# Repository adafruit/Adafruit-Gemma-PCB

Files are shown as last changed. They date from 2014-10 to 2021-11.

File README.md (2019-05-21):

## Adafruit Gemma Classic (ATtiny85) PCB
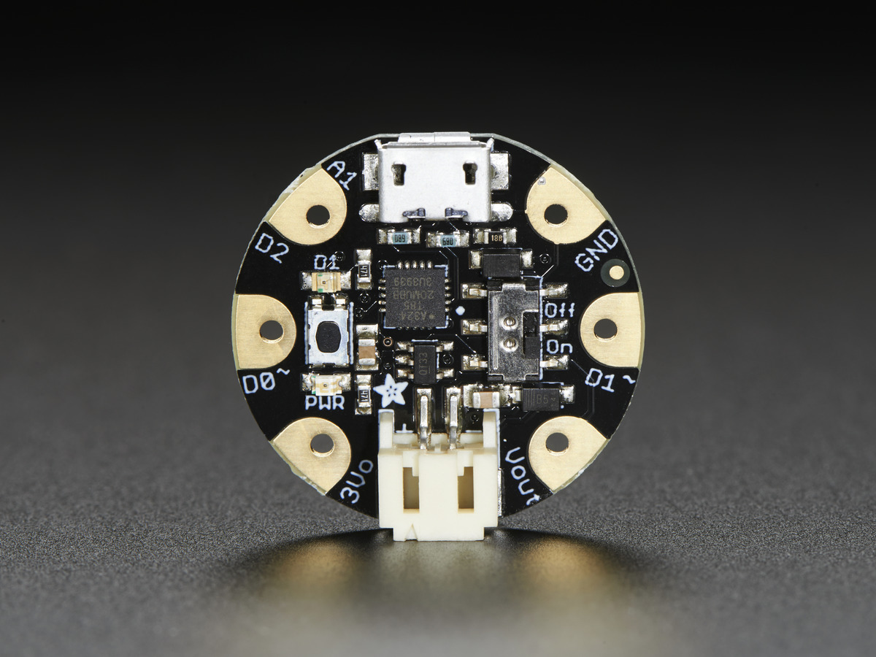
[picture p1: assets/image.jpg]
<a href="http://www.adafruit.com/products/1222"><br/>
Click here to purchase one from the Adafruit shop</a>

Deprecation Warning: The Gemma bit-bang USB technique it uses doesn't work as well as it did in 2014, many modern computers won't work well. So while we still carry the Gemma so that people can maintain some older projects, we no longer recommend it. Please check out the Gemma M0. It has built-in USB, more capabilities, and is comparable in price!

GEMMA is a tiny wearable platform board with a lot of might in a 1" diameter package. Powered by a Attiny85 and programmable with an Arduino IDE over USB, you'll be able to realize any wearable project!

We wanted to design a microcontroller board that was small enough to fit into any project, and low cost enough to use without hesitation. Perfect for when you don't want to give up your Flora and you aren't willing to take apart the project you worked so hard to design. It's our lowest-cost sewable controller!

The Attiny85 is a fun processor because despite being so small, it has 8K of flash, and 5 I/O pins, including analog inputs and PWM 'analog' outputs. We designed a USB bootloader so you can plug it into any computer and reprogram it over a USB port just like an Arduino (it uses 2 of the 5 I/O pins, leaving you with 3). In fact we even made some simple modifications to the Arduino IDE so that it works like a mini-Flora. Perfect for small & simple projects the GEMMA will be your go-to wearable electronics platform.

This is the CAD & PCB data for the Adafruit Gemma. The PCB format is EagleCAD schematic and board layout

For more details, check out the product page at
- https://www.adafruit.com/products/1222

### License

Adafruit invests time and resources providing this open source design, please support Adafruit and open-source hardware by purchasing products from [Adafruit](https://www.adafruit.com)!

All text above must be included in any redistribution

Designed by Limor Fried/Ladyada for Adafruit Industries.
Creative Commons Attribution/Share-Alike, all text above must be included in any redistribution. 
See license.txt for additional information.

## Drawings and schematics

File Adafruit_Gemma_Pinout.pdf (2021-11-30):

# Gemma

# https://www.adafruit.com/products/1222

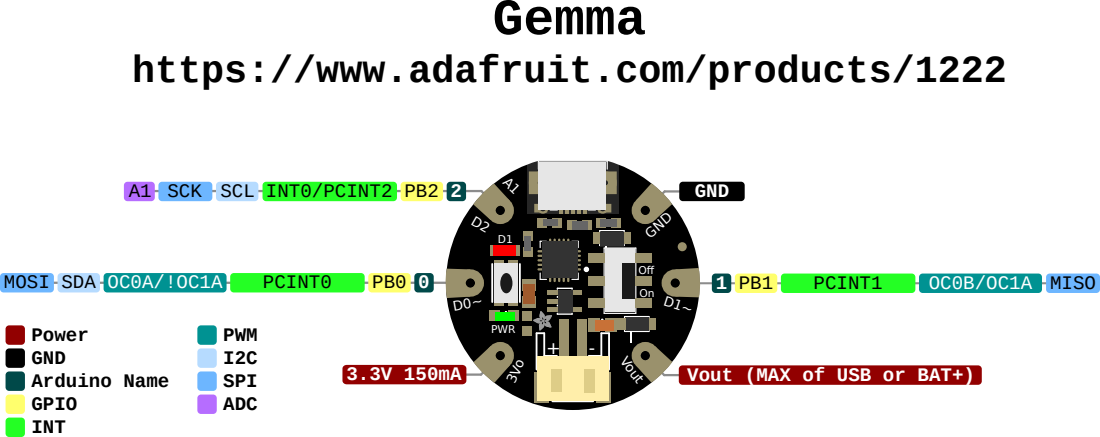
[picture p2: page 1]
PCINT1; OC0B/OC1A MISO; GND; A1 SCK SCL INT0/PCINT2 PB2 2; MOSI SDA OC0A/!OC1A; PCINT0; Vout; PWR; Off; Power GND Arduino Name GPIO INT; PWM I2C SPI ADC

Vout (MAX of USB or BAT+)

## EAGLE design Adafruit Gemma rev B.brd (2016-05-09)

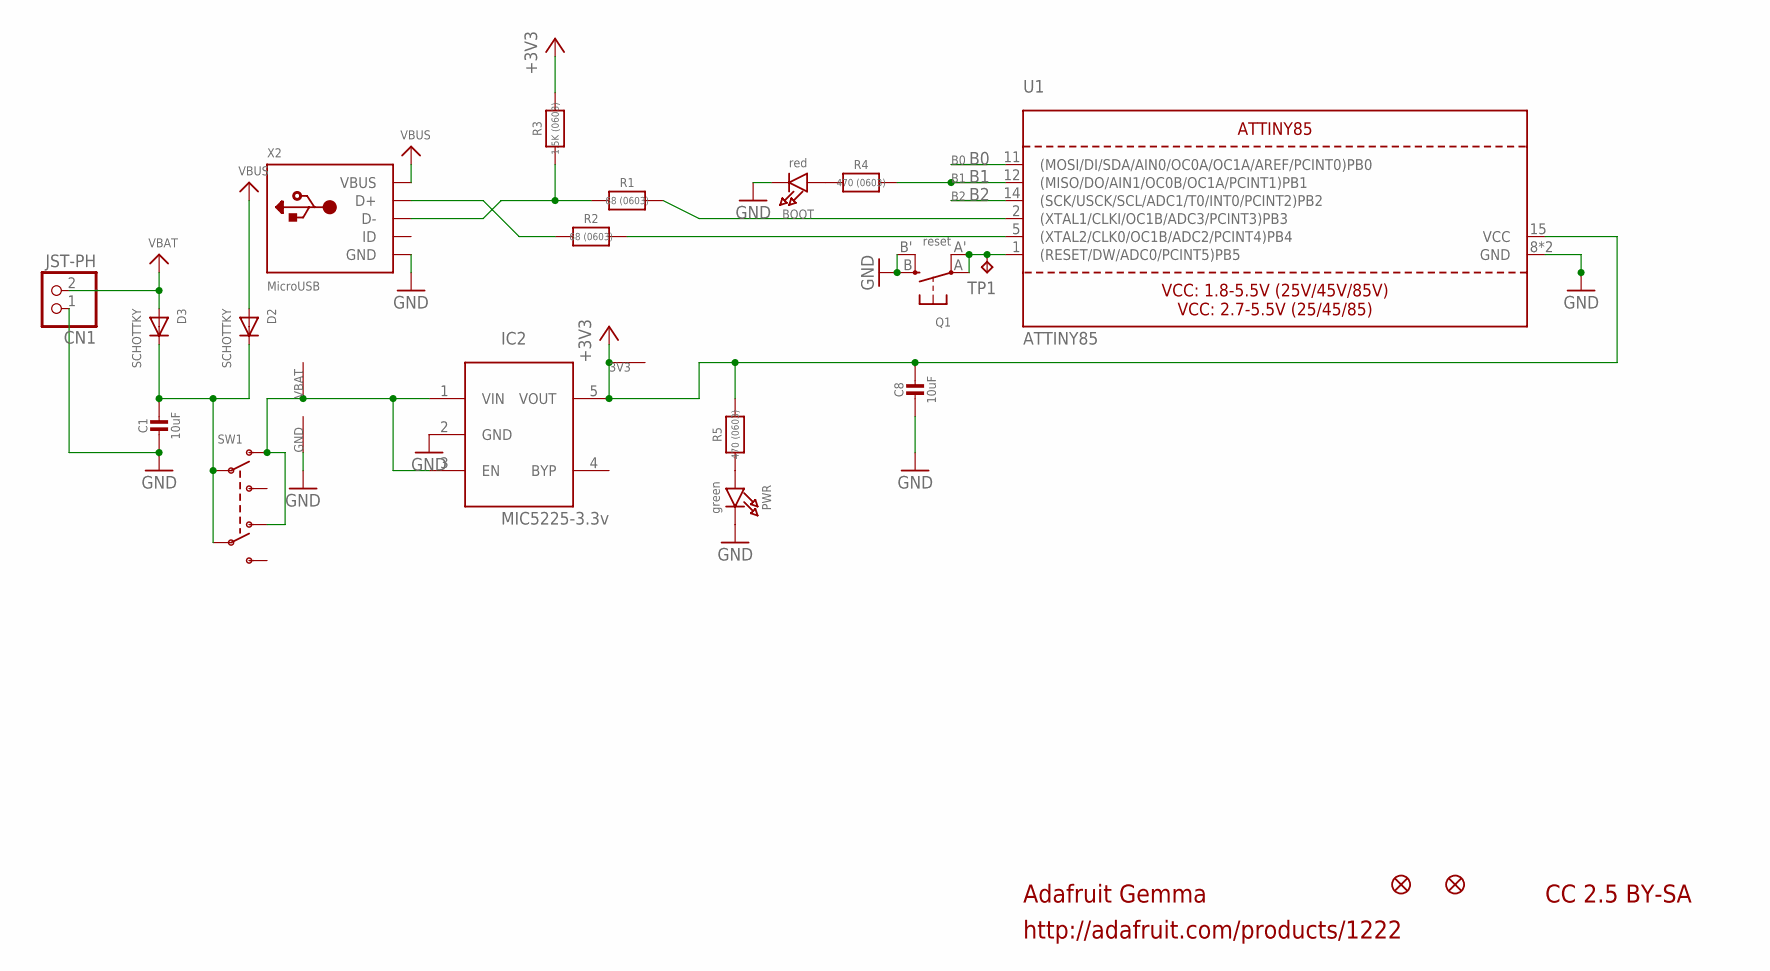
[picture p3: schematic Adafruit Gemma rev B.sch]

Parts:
3V3: SEWTAP-2.0IN; SEWINGTAP_2.0
B0, B1, B2: SEWTAP-2.0IN; SEWINGTAP_2.0
BOOT: red; CHIPLED_0805_NOOUTLINE
C1, C8: 10uF; 0805-NO
CN1: JST-PH; JSTPH2
D2, D3: SCHOTTKY; SOD-123FL
GND: SEWTAP-2.0IN; SEWINGTAP_2.0
IC2: MIC5225-3.3v; SOT23-5L
PWR: green; CHIPLED_0805_NOOUTLINE
Q1: reset; BTN_KMR2_4.6X2.8
R1, R2: 68 (0603); 0603-NO
R3: 1.5K (0603); 0603-NO
R4, R5: 470 (0603); 0603-NO
SW1: SWITCH_DPDTEG1390; EG1390
TP1: TPB2,54; B2,54
U1: ATTINY85; MLF20_4X4MM_0.5MM_ATMEL
U$1, U$6: FIDUCIAL""; FIDUCIAL_1MM
VBAT: SEWTAP-2.0IN; SEWINGTAP_2.0
X2: MicroUSB; 4UCONN_20329

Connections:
+3V3: 3V3.P$1, C8.1, IC2.5 (VOUT), R3.2, R5.2, U1.15 (VCC)
B0: B0.P$1, U1.11 ((MOSI/DI/SDA/AIN0/OC0A/OC1A/AREF/PCINT0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)
B1: B1.P$1, R4.2, U1.12 ((MISO/DO/AIN1/OC0B/OC1A/PCINT1)PB1)
B2: B2.P$1, U1.14 ((SCK/USCK/SCL/ADC1/T0/INT0/PCINT2)PB2)
GND: BOOT.C, C1.2, C8.2, CN1.1, GND.P$1, IC2.2 (GND), PWR.C, Q1.B (S), Q1.B' (S1), U1.8 (GND), U1.THERMAL (GND), X2.BASE@1 (GND), X2.BASE@2 (GND), X2.GND, X2.SPRT@1 (GND), X2.SPRT@2 (GND), X2.SPRT@3 (GND), X2.SPRT@4 (GND)
unnamed: Q1.A, Q1.A' (P1), TP1.TP, U1.1 ((RESET/DW/ADC0/PCINT5)PB5)
unnamed: R2.1, X2.D+
unnamed: R1.2, U1.2 ((XTAL1/CLKI/OC1B/ADC3/PCINT3)PB3)
unnamed: R2.2, U1.5 ((XTAL2/CLK0/OC1B/ADC2/PCINT4)PB4)
unnamed: R1.1, R3.1, X2.D-
unnamed: BOOT.A, R4.1
unnamed: IC2.1 (VIN), IC2.3 (EN), SW1.O1, SW1.O2, VBAT.P$1
unnamed: PWR.A, R5.1
unnamed: C1.1, D2.C, D3.C, SW1.P1, SW1.P2
VBAT: CN1.2, D3.A
VBUS: D2.A, X2.VBUS

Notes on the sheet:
Adafruit Gemma
http://adafruit.com/products/1222
CC 2.5 BY-SA

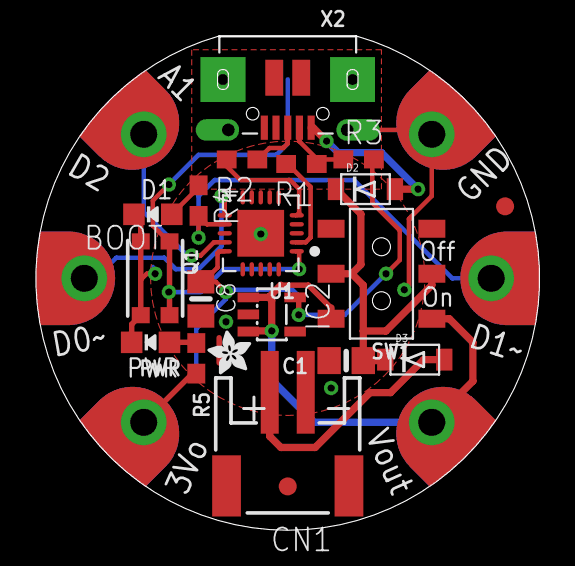
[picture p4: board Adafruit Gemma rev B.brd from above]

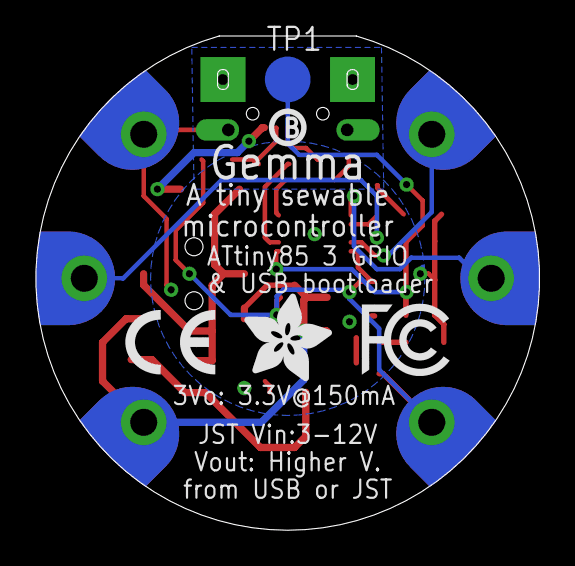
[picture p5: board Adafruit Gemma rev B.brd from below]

Board: 2 copper layers, 28.0 x 27.5 mm, 31 parts (5 on the bottom side), 16 nets.

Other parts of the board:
U$2: ADAFRUIT_2.5MM
U$7: ADAFRUIT_5MM
U$8: SYMBOL_FCC_5MM
U$9: SYMBOL_CE_5MM
U$10: PCBFEAT-REV-040

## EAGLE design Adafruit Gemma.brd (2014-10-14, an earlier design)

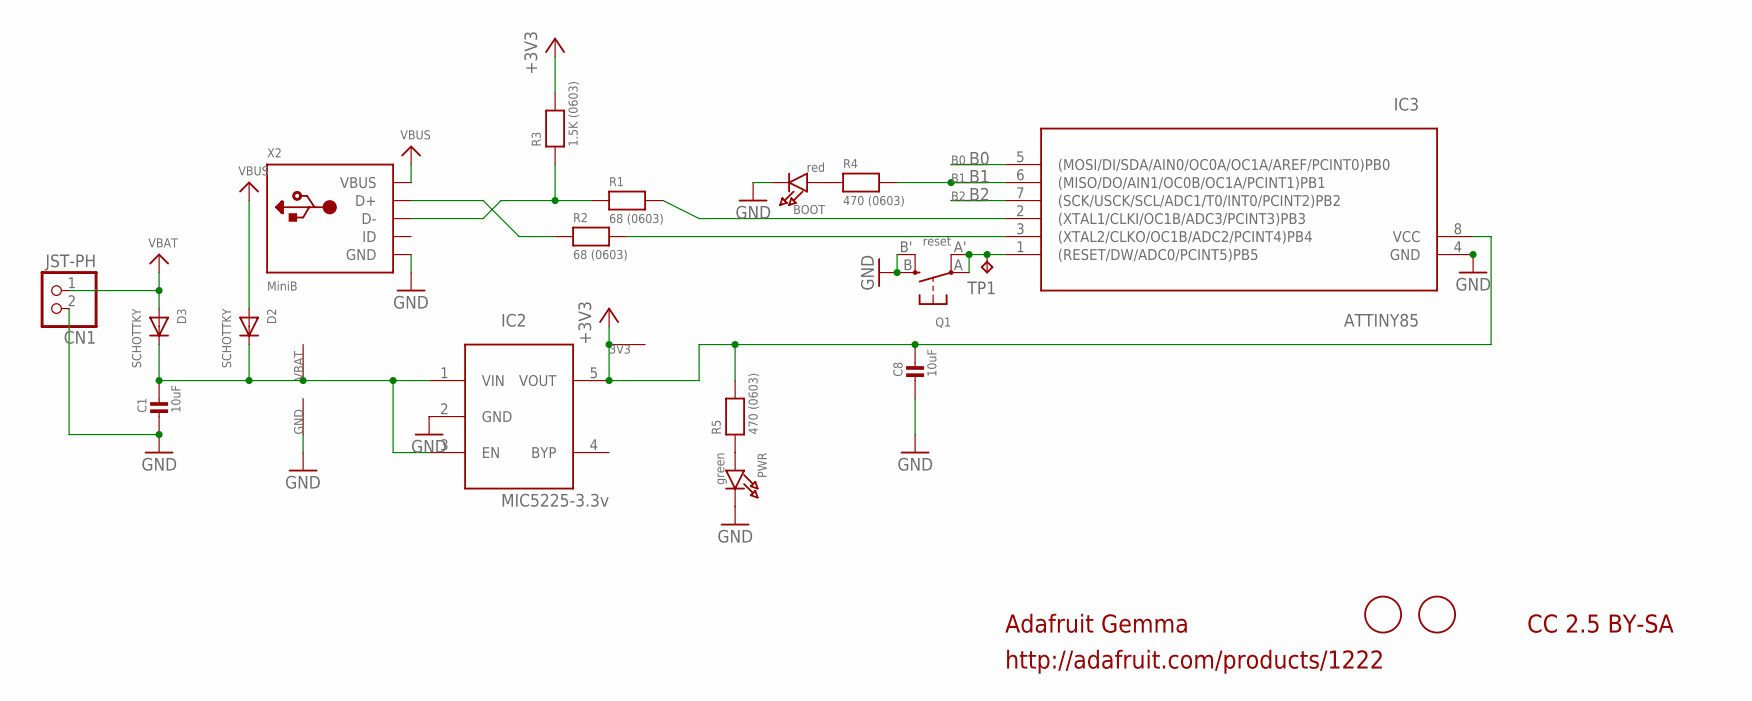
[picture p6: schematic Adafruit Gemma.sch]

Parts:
3V3: SEWTAP-2.0IN; SEWINGTAP_2.0
B0, B1, B2: SEWTAP-2.0IN; SEWINGTAP_2.0
BOOT: red; CHIPLED_0805_NOOUTLINE
C1, C8: 10uF; 0805-NO
CN1: JST-PH; JST-PH-2-SMT-RA
D2, D3: SCHOTTKY; SOD-123FL
GND: SEWTAP-2.0IN; SEWINGTAP_2.0
IC2: MIC5225-3.3v; SOT23-5L
IC3: ATTINY85; SOIC8
PWR: green; CHIPLED_0805_NOOUTLINE
Q1: reset; BTN_KMR2_4.6X2.8
R1, R2: 68 (0603); 0603-NO
R3: 1.5K (0603); 0603-NO
R4, R5: 470 (0603); 0603-NO
TP1: TPB2,54; B2,54
U$1, U$6: FIDUCIAL; FIDUCIAL_1MM
VBAT: SEWTAP-2.0IN; SEWINGTAP_2.0
X2: MiniB; USB-MINI_MEDIUM

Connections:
+3V3: 3V3.P$1, C8.1, IC2.5 (VOUT), IC3.8 (VCC), R3.2, R5.2
B0: B0.P$1, IC3.5 ((MOSI/DI/SDA/AIN0/OC0A/OC1A/AREF/PCINT0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)
B1: B1.P$1, IC3.6 ((MISO/DO/AIN1/OC0B/OC1A/PCINT1)PB1), R4.2
B2: B2.P$1, IC3.7 ((SCK/USCK/SCL/ADC1/T0/INT0/PCINT2)PB2)
GND: BOOT.C, C1.2, C8.2, CN1.2 (1), GND.P$1, IC2.2 (GND), IC3.4 (GND), PWR.C, Q1.B (S), Q1.B' (S1), X2.GND, X2.GND1 (GND), X2.GND2 (GND), X2.GND3 (GND), X2.GND4 (GND)
unnamed: IC3.1 ((RESET/DW/ADC0/PCINT5)PB5), Q1.A, Q1.A' (P1), TP1.TP
unnamed: R2.1, X2.D+
unnamed: IC3.2 ((XTAL1/CLKI/OC1B/ADC3/PCINT3)PB3), R1.2
unnamed: IC3.3 ((XTAL2/CLKO/OC1B/ADC2/PCINT4)PB4), R2.2
unnamed: R1.1, R3.1, X2.D-
unnamed: BOOT.A, R4.1
unnamed: C1.1, D2.C, D3.C, IC2.1 (VIN), IC2.3 (EN), VBAT.P$1
unnamed: PWR.A, R5.1
VBAT: CN1.1 (2), D3.A
VBUS: D2.A, X2.VBUS

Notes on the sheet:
Adafruit Gemma
http://adafruit.com/products/1222
CC 2.5 BY-SA

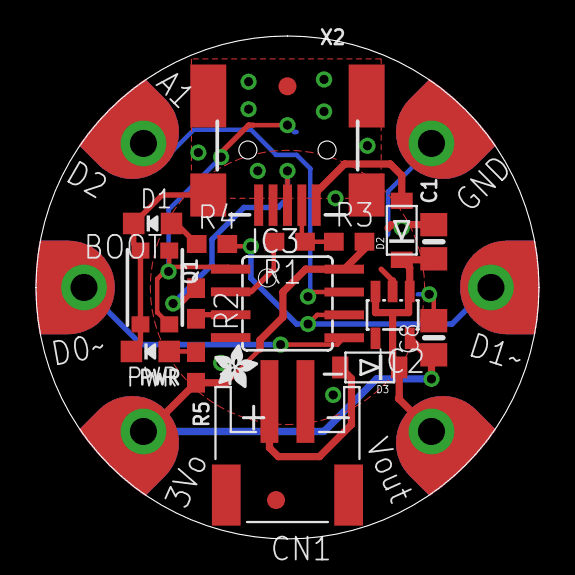
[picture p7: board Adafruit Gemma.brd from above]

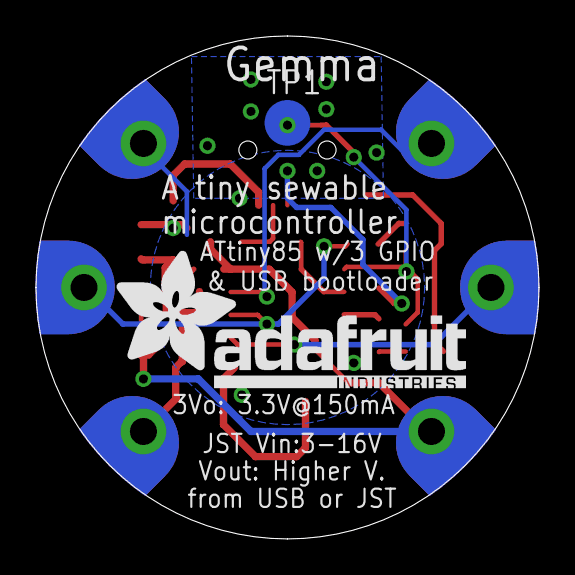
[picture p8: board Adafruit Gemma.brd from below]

Board: 2 copper layers, 27.9 x 27.9 mm, 27 parts (2 on the bottom side), 15 nets.

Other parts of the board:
U$2: ADAFRUIT_2.5MM
U$7: ADAFRUIT_TEXT_20MM

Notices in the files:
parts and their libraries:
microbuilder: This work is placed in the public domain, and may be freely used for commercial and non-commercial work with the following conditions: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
